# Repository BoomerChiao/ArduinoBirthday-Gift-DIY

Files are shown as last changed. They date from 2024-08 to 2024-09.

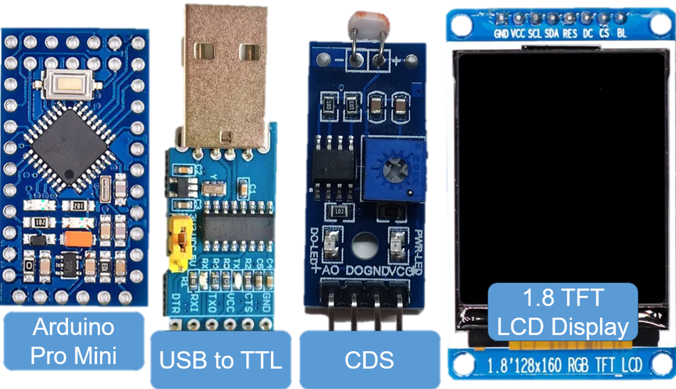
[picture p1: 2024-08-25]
JPG/Materials-A.png

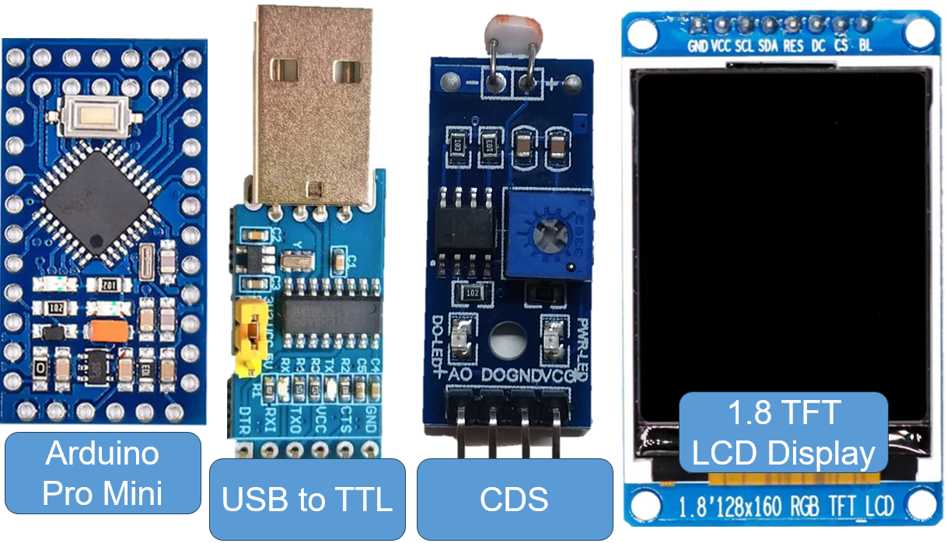
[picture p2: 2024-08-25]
JPG/Materials.png

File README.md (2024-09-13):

##  Summary　（概要）

Arduino Interactive Gifts is a compact interactive gift that features an Arduino Pro Mini microcontroller board, a TFT color LCD screen (supporting 18-bit color depth), and multiple light-dependent resistors (LDRs).

###  中文
Arduino Interactive Gifts 是一款小型互動式禮物，搭載 Arduino Pro Mini 微控制器板和 TFT 彩色液晶顯示螢幕（支持 18 位色深），並配備多顆光敏電阻（LDRs）。

##  Installation　（安裝）
Install Arduino software
- Arduino software downloads：https://www.arduino.cc/en/software
									
###  中文
安裝 Arduino 軟體
- Arduino 軟體下載：https://www.arduino.cc/en/software



##  Import data　（導入資料）
1. Download GitHub Data or Create a New Arduino Project:
   - You can either download the necessary files from GitHub or start a new Arduino project.

2. Include the Required Arduino Libraries:
   - To add extra functionality, move the required Arduino library files to your project. You can download these libraries from the "Library" folder on GitHub.
   - Alternatively, open the Arduino IDE, go to the 「Sketch」 menu, and select 「Include Library」→「Manage Libraries...」 to access and install the libraries.

3. Import the Libraries:
   - After importing the function libraries, select the project you wish to work on and integrate the necessary code.

###  中文
1. 下載 GitHub 資料或創建新 Arduino 專案：
   - 你可以從本網的 GitHub 下載所需的資料，或是自行創建一個新的 Arduino 專案。
    
2. 導入必要的程式函數庫：
   - 將必要的函數庫文件從 GitHub 的“Library”資料夾中下載並安裝至指定位置。
   - 你也可以在 Arduino IDE 中選擇「草稿碼」→「匯入程式庫」→「管理程式庫...」，然後下載所需的程式函數庫。

3. 完成函數庫導入後：
   - 選擇你要製作的專案並直接開啟即可開始使用。

##  Prepare Electronic Materials　（準備電子材料）
1. Arduino Pro Mini (5V/16M)
2. USB to UART Adapter (FTDI or CP2102)
3. TFT LCD Display Module (Icstation 1.8 Inch TFT LCD Screen 128x160 ST7735)
4. CDS (5mm)
5. Jumper Wires


##  Pin wiring　（引腳接線）

⬆The above diagram shows the pin connection schematic.

- Please note that the LCD supports only a 3.3 ~ 5V voltage. Therefore, it is recommended to set the VCC to be powered by a 5V supply.
- The quantity of photoresistors can be adjusted according to specific requirements, with support for up to 3 units.
- The TOUCH button A0 is a Jumper wire.

###  中文
- 請注意，該 LCD 僅持支援 3.3 ~ 5V 電壓範圍。因此，建議將 VCC 預設為 5V 電源以確保正常運作。
- 光敏電阻數量可以根據具體需求進行調整。（最多支援 3 顆）
- 觸控按鈕 (TOUCH) A0是一根跳線。

##  Program Code　（程式代碼）
This project utilizes online-provided code libraries for management and display. To ensure that the code runs correctly, please install the 「Adafruit ST7735 and ST7789 Library」 and 「ADCTouch」 in advance.

This code provides three different programming approaches. You can choose the most suitable option based on your needs to develop your final product. Below is an overview of the differences between each code option:
1. Arduino_TFT：
   - Features: Provides basic TFT display animation technology and ADCTouch interaction.
   - Use Case: Suitable for applications that require basic display and touch functionalities.
  
2. Arduino_TFT_CDS：
   - Features: Builds on the basic TFT display animation and ADCTouch interaction, with the addition of a Light Dependent Resistor (CDS) to detect ambient light levels and automatically adjust the display's on/off state.
   - Use Case: Ideal for applications that require ambient light detection and automatic display control.
  
3. Arduino_TFT_CDS_CPUandReset：
   - Features: Expands upon the basic TFT display animation and ADCTouch interaction by incorporating a CDS sensor to detect ambient light and automatically control the display's power state. Additionally, when the display is off, the system activates a low-power CPU mode to extend battery life.
   - Use Case: Suitable for applications requiring light detection, automatic display control, and power-saving features.

You can download the code from the following link：https://github.com/BoomerChiao/ArduinoBirthday-Gift-DIY/tree/main/Code

###  中文
本次專題採用了網上提供程式數據庫進行管理和顯示，為了確保代碼能夠正確運行，請事先安裝以下程式庫：
1. Adafruit ST7735 Library
   - 用途：提供 ST77xx TFT 顯示模組的控制支持。
   - 安裝方式如下
     - 打開 Arduino IDE 點擊「工具」 > 「管理庫...」。
     - 在程式庫管理器的搜索框中輸入 "Adafruit ST7735"。
     - 在搜尋結果中找到 "Adafruit ST7735 and ST7789 Library" 點擊 「安裝」 按鈕。
     

2. ADCTouch Library
   - 用途：用於讀取觸控傳感器的數據。
   - 安裝方式如下
     - 打開 Arduino IDE 點擊「工具」 > 「管理庫...」。
     - 在程式庫管理器的搜索框中輸入 "ADCTouch"。
     - 在搜尋結果中找到 "ADCTouch" 點擊 「安裝」 按鈕。
     

該代碼提供3種不同的程式方式，你可以根據需求選擇最適合的方式來製作你的最終產品。以下是每種程式碼選項的差異介紹：
1. Arduino_TFT：
   - 功能：提供基本的 TFT 顯示動畫技術和 ADCTouch 觸控互動。
   - 適用場景：適合需要基本顯示和觸控功能的應用。
2. Arduino_TFT_CDS：
   - 功能：基於基本 TFT 顯示動畫和 ADCTouch 觸控互動的基礎上，增加了光敏電阻（CDS）來檢測環境光源，並決定是否自動調節顯示螢幕的開關狀態。
   - 適合需要環境光檢測以及顯示螢幕自動控制的應用場景。
3. Arduino_TFT_CDS_CPUandReset：
   - 功能：在基本 TFT 顯示動畫和 ADCTouch 觸控互動的基礎上，增加了光敏電阻（CDS）以檢測環境光源並自動控制顯示螢幕開關。此外，當顯示螢幕關閉時，系統將啟用低功耗的 CPU 模式，以提高電池續航能力。
   - 適用於需要光檢測、自動顯示控制和節能功能的應用。

你可以從以下鏈接下載代碼：https://github.com/BoomerChiao/ArduinoBirthday-Gift-DIY/tree/main/Code

.

.

P.S. 其他安裝Library
   - 打開 Arduino IDE 點擊「sketch」 > 「程式庫」 > 「加入.Zip程式庫...」。
   - 搜尋 已下載Zip程式庫 ，點擊 「開啟」 按鈕。

P.S. Code is customizable （可自定義代碼）

1. (TFT_sleep=75) This parameter sets the brightness threshold for the light-dependent resistor (CDS) to determine the on/off state of the display (TFT). 
（參數用於設定光敏電阻 (CDS) 的亮度閾值，以決定顯示器 (TFT) 的開關狀態。）

   - A higher value indicates that a greater ambient light level is required to keep the display on, meaning the display will stay on in bright conditions. Conversely, a lower value will cause the display to remain on even in lower light conditions.
     （數值越大，表示所需的環境亮度越高，顯示器在光線充足時將保持開啟；數值越小，則顯示器在光線較弱時也會開啟。）
   - If the parameter is set to -1, the light-dependent resistor (CDS) is disabled, and the display will remain on at all times.
     （若參數設定為 -1，則光敏電阻 (CDS) 會被禁用，顯示器將始終保持開啟狀態。）

3. (walk_delay=230) This parameter adjusts the delay time for character movement. A smaller value results in faster movement, while a larger value slows down the movement.
   （參數用於調整人物行走的延遲時間。數值越小，人物行走的速度越快；數值越大，人物行走的速度則越慢。）

##  Arduino Pro or Pro Mini USB to UART Hookup Guide　（Arduino Pro、Pro Mini USB 燒入連接指南）
The Arduino Pro Mini and Arduino Pro are compact, low-power versions of the Arduino board. To program these boards or communicate with them via a computer, you'll need a USB-to-UART (Universal Asynchronous Receiver/Transmitter) adapter.


Picture from：https://www.b4x.com/android/forum/threads/how-to-connect-an-arduino-pro-mini-to-a-pc-via-a-usb-to-serial-module.77010/
1. Steps to Connections
   - USB-to-UART Adapter VCC → Arduino Pro Mini VCC
     - USB-to-UART Adapter Pins Connect to Arduino Pro Mini VCC (make sure it matches the voltage of your Pro Mini)
   - USB-to-UART Adapter GND → Arduino Pro Mini GND
   - USB-to-UART Adapter TX → Arduino Pro Mini RX
   - USB-to-UART Adapter RX → Arduino Pro Mini TX
   - USB-to-UART Adapter DTR → Arduino Pro Mini DTR
2. Troubleshooting Tips
   - Check Connections： Ensure all wires are connected securely and to the correct pins.
   - Verify Voltage： Make sure the VCC connection matches the voltage requirements of your Pro Mini.
   - Auto-reset： If uploading code fails, try manually pressing the reset button on the Pro Mini just before uploading.

##  Advanced Design　（進階設計）
To simplify the electronic manufacturing process, we employed the printed etch resist method to handle complex and difficult-to-connect circuits. This approach not only significantly reduces the risk of incorrect connections but also ensures the effective operation of the product.

Therefore, we utilized the PCB manufacturing services provided by EasyEDA to successfully address the challenges of printed circuit design for this project.

為了簡化電子製作過程，我們採用了印刷蝕刻阻劑工法來處理複雜且難以連接的線路。這樣不僅能大幅度降低錯誤連接的風險，還能確保產品的有效運作。

因此，我們利用了EasyEDA提供的PCB製造服務，成功解決了此專案中的印刷電路設計挑戰。

You can obtain the PCB layout from the following link（你可以從下鏈結獲得PCB layout）：https://oshwlab.com/chiaochieh/dinotaeng_gift_2024-06-04_21-21-12

###  Circuit Design （電路設計）
   

###  PCB layout （電路布局）
   

###  PCB Prepare Electronic Materials　（PCB準備電子材料）
1. SMD MLCC 
   - C1、C4、C8：100nF-1206
   - C2、C3、C7、C9：10uF-1206
   - C5：47uf-50v or 100uf-25v or N/A

2. SMD Resistors
   - R1：130Ω-1206
   - R2：390Ω-1206
   - R3、R4：5.1KΩ-1206
   - R5、R6、R7：GL7537 or 5mm_CDS
   - R8、R9、R10：1KΩ-1206
   - F1：TLC-MSMD160/6 or 0Ω-1812

3. DIP Connectors 
   - P1、P2、P4：N/A
   - P3：2.54mm Plugin Straight Headers Connector 2x7P、1x10P、1x10P
   - P5：2.54mm Plugin 8P Straight 1x8P Headers Connector
   - P6、P7：2.54mm Plugin 3P Straight 1x3P Pin Headers or 3P slide switch
   - P8：2.54mm Plugin 2P Straight 1x2P Pin Headers

4. SMD Active component
   - D1：SS34 (SMA) or 1N4007_SMD (M7 or SMA)
   - U1：AMS1117-ADJ
   - U2：AMS1117-3.3
   - TVS：SMBJ5.0CA or N/A

5. Power Connector
   - USB：KH-TYPE-C-6P-T or SMD TYPE C 6P
   - DC:XDJK-0051-025 or DIP DC Power Connectors (2.1mm 6.3mm)

###  3D casing （3D外殼）
To facilitate wiring and prevent cable damage, the V1 version includes dedicated cable routing openings.
（為了提高布線的便利性並減少線材損壞的風險，V1版本設計了專用的走線開口。）



You can obtain the 3D printed shell from the following link（你可以從下鏈結獲得3D外殼）：
https://www.thingiverse.com/thing:6763818

##  Product Showcase　（成品展示）
















##  References　（參考資料）
1. https://www.arduino.cc/en/software
2. https://www.b4x.com/android/forum/threads/how-to-connect-an-arduino-pro-mini-to-a-pc-via-a-usb-to-serial-module.77010/
3. https://github.com/adafruit/Adafruit-ST7735-Library
4. https://github.com/martin2250/ADCTouch

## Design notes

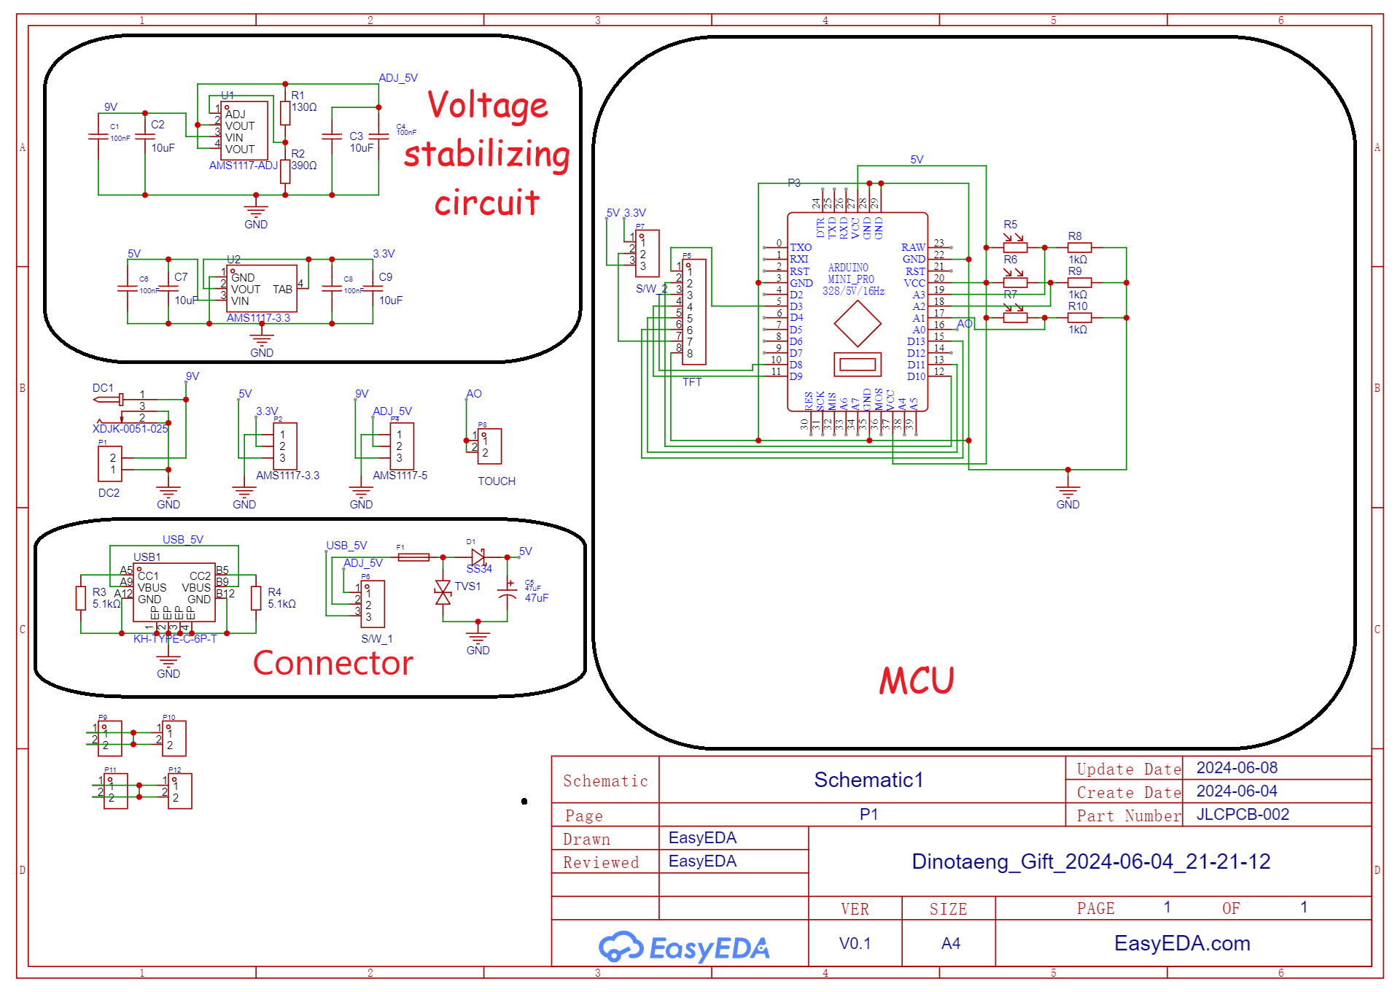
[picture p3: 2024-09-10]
JPG/Circuit.png

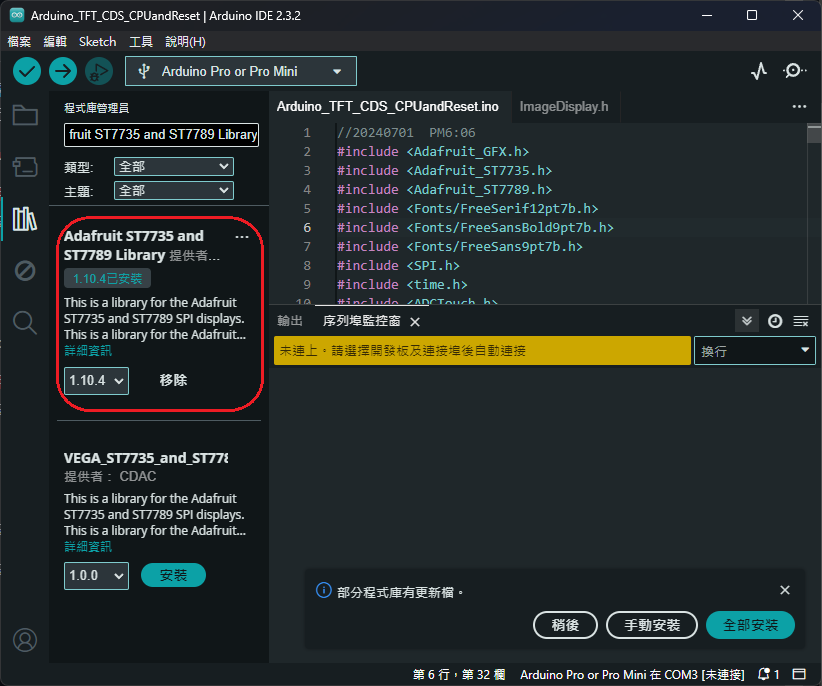
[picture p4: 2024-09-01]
JPG/Library_A.png

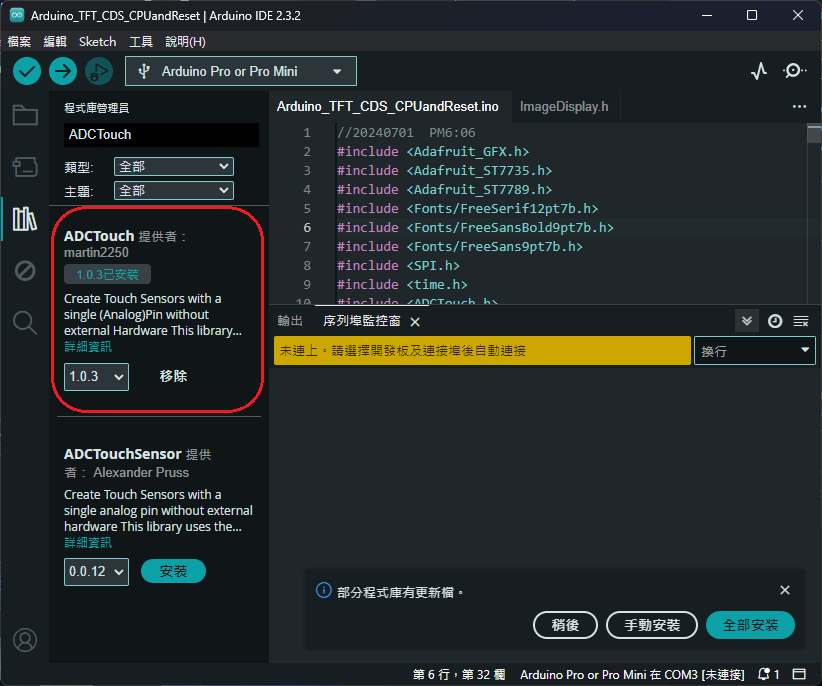
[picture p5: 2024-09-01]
JPG/Library_B.png

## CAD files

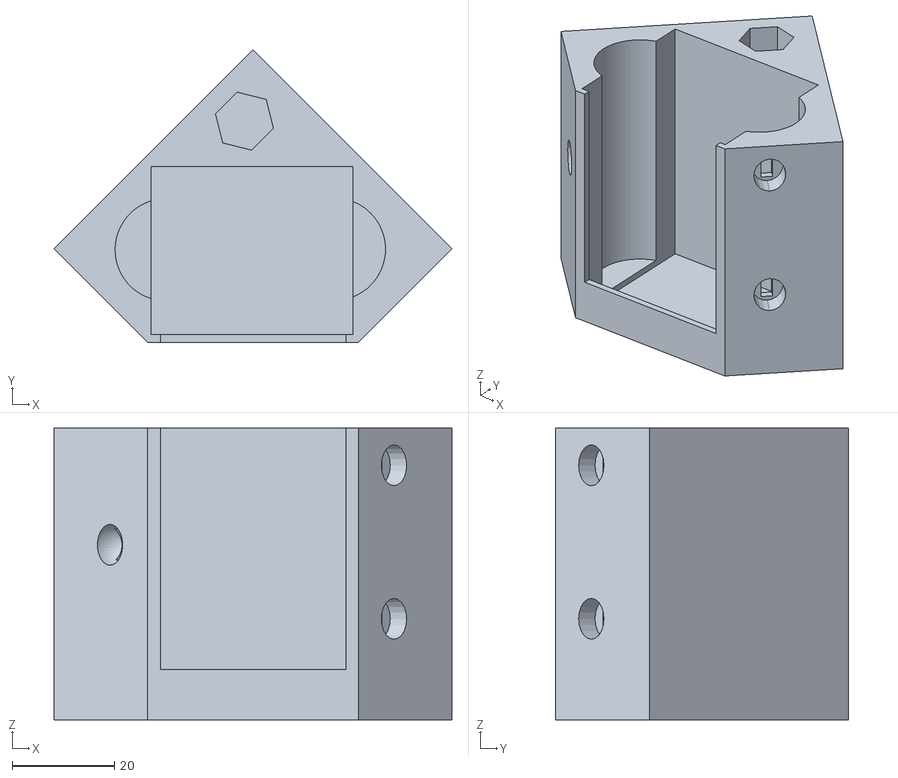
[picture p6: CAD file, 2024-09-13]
3D Printing/3D_printed_shell_A_V1.stl
77.8 x 57.2 x 57.0

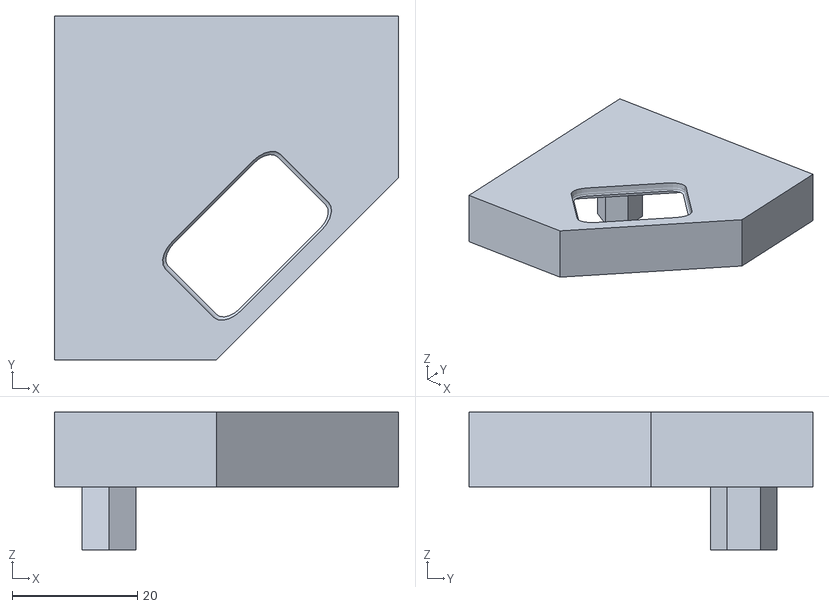
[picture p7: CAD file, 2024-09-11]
3D Printing/3D_printed_shell_B.stl
55.0 x 55.0 x 22.0

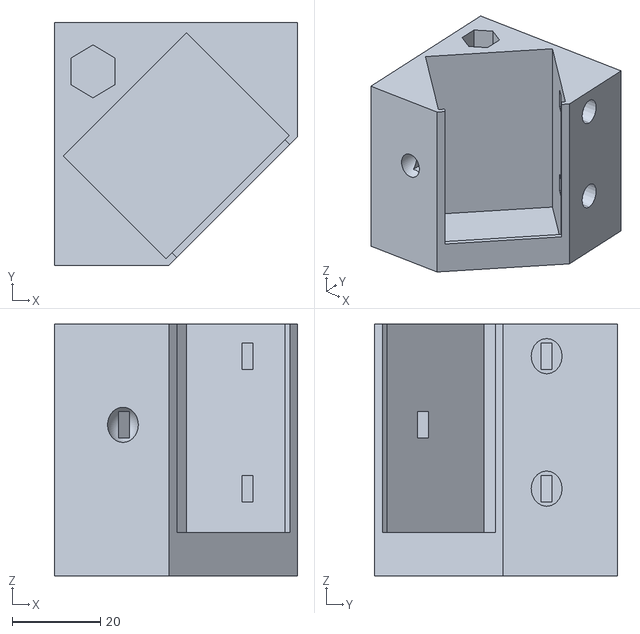
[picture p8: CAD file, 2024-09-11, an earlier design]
3D Printing/3D_printed_shell_A.stl
55.0 x 55.0 x 57.0

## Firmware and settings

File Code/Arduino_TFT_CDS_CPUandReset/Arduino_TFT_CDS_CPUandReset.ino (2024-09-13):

//20240701  PM6:06
#include <Adafruit_GFX.h>
#include <Adafruit_ST7735.h>
#include <Adafruit_ST7789.h>
#include <Fonts/FreeSerif12pt7b.h>
#include <Fonts/FreeSansBold9pt7b.h>
#include <Fonts/FreeSans9pt7b.h>
#include <SPI.h>
#include <time.h>
#include <ADCTouch.h>
#include <avr/wdt.h> //watchdog 
#include "ImageDisplay.h"
#define TFT_CS  10 // TFT CS PIN
#define TFT_DC   8 // TFT DC(A0、RS) 
#define TFT_RST  9 // TFT Reset

int walk=0,Gift_X,Gift_Y,time_sun_moon; 
int CDS_A,CDS_B,CDS_C,CDS_Time=0 ,TFT_sleep=75; //CDS The higher the value, the stronger the light source required.
int TOUCH_A0;     //reference values to remove offset
int walk_delay=230; //Modify the timing of the steps
bool Gift_bool = false , sun_moon=false , TFT_sleep_bool=true;   //true,false

Adafruit_ST7735 tft = Adafruit_ST7735(TFT_CS, TFT_DC, TFT_RST);


void setup(void) {
  
  
  // 1.8" TFT:
  tft.initR(INITR_BLACKTAB);      // Init ST7735S chip, black tab

  // 1.44" TFT:
  //tft.initR(INITR_144GREENTAB); // Init ST7735R chip, green tab


  srand( time(NULL) );
  TOUCH_A0 = ADCTouch.read(A0, 200);
  tft.setRotation(1);  //螢幕轉向 screen orientation
  tft.fillScreen(ST77XX_BLACK);  //填滿黑色
  tft.fillRect(0, 0, 160, 87,0x6358); //Sky
  tft.fillRect(0, 87, 160, 41,0x0568); //floor
  pinMode(3,OUTPUT); //TFT BLK on/off
  wdt_enable(WDTO_8S); //Watchdog 
  digitalWrite(3,LOW);

}

void loop() {
  int value0 = ADCTouch.read(A0);   //no second parameter
  value0 -= TOUCH_A0;       //remove offset
  CDS_A = analogRead(A1);CDS_B = analogRead(A2);CDS_C = analogRead(A3);

  if (TFT_sleep_bool==false || CDS_A>TFT_sleep || CDS_B>TFT_sleep || CDS_C>TFT_sleep)
  {

    CLKPR = 1 << CLKPCE;
    CLKPR = 0;// 將CPU速度設定為 16MHz/1   Set the CPU speed to 16 MHz / 1
    sun_moon_display();
    Quokka_BOBO_display();

  if(value0 > 60 && Gift_bool == true ) //Touch A0
  {
  Gift_display();
  }
  if(CDS_A<=TFT_sleep && CDS_B<=TFT_sleep && CDS_C<=TFT_sleep)
  {
    CDS_Time = CDS_Time+1;
    if(CDS_Time>5)
    {
      TFT_sleep_bool=true;
      CDS_Time=0;
    }} 
    else
    {
      CDS_Time=0;
      TFT_sleep_bool=false;
    } 
    
    digitalWrite(3,HIGH);
    }
  else if (TFT_sleep_bool==true && CDS_A<=TFT_sleep && CDS_B<=TFT_sleep && CDS_C<=TFT_sleep)
  {
    digitalWrite(3,LOW);
    CLKPR = 1 << CLKPCE;
    CLKPR = 8;// 將CPU速度設定為 62.5KMHz/256  Set the CPU speed to 62.5 KHz / 256
  }
  wdt_reset();
  }




void Quokka_BOBO_display(void)
{
  if(walk>160) 
  {
    walk=-68;
    Gift_bool = true;
    Gift_X= rand()%(143 - 1 + 1) + 1; // (max - min + 1) + min
    Gift_Y= rand()%(31 - 1 + 1) + 1; // (max - min + 1) + min
    tft.drawRGBBitmap(Gift_X, Gift_Y+88,Gift, 16, 7);
    //tft.drawRGBBitmap(0, 0,Gift, 16, 7);
    //tft.fillRect(0, 0, 18, 9,ST77XX_GREEN);
  }

  tft.fillRect(walk+0, 39, 11, 48,0x6358);
  tft.drawRGBBitmap(walk+0, 40,BB, 32, 31);
  //tft.drawRGBBitmap(walk+11, 71,BC, 26, 16);//x,y,png,xx,yy
  tft.drawRGBBitmap(walk+11, 71,BD, 26, 16);

  tft.fillRect(walk+31, 59, 10, 13,0x6358);
  tft.drawRGBBitmap(walk+36, 60,DB, 20, 13);
  //tft.drawRGBBitmap(walk+37, 71,DC, 18, 14);
  tft.drawRGBBitmap(walk+37, 73,DD, 18, 14);
  //delay(230);
  delay(walk_delay);

/*tft.drawRGBBitmap(walk+11, 71,BD, 26, 16);
  tft.drawRGBBitmap(walk+37, 71,DD, 18, 14);*/
  tft.drawRGBBitmap(walk+11, 71,BC, 26, 16);
  tft.drawRGBBitmap(walk+37, 73,DC, 18, 14);
  //delay(230);
  delay(walk_delay);
  tft.fillRect(walk+0, 39, 11, 48,0x6358);
  walk=walk+8;
  //tft.fillRect(walk+31, 58, 10, 13,ST77XX_BLACK);
}


void sun_moon_display(void)
{
  tft.fillRect(time_sun_moon*2.7-2, 0, 22, 30,0x6358); //Reset sun_moon track
  time_sun_moon=time_sun_moon+1; //sun_moon time
  
  if(time_sun_moon>60)
  {
    time_sun_moon=-10  ;
    if(sun_moon == false)
    {
      sun_moon = true;
      tft.fillRect(0, 0, 160, 30,0x6358);
    }
    else
    {
      sun_moon = false;
    }
  }
  
  
  if(sun_moon == false)
  {
    Gift_X= rand()%(160 - 1 + 1) + 1; // (max - min + 1) + min
    Gift_Y= rand()%(28 - 1 + 1) + 1; // (max - min + 1) + min
    //tft.drawRGBBitmap(Gift_X, Gift_Y+88,Gift, 16, 7);
    tft.fillCircle(Gift_X, Gift_Y, 1, ST77XX_WHITE); 
    //tft.drawRGBBitmap(time_sun_moon*2.7-10, 3,sun_moon_B, 11, 22);
    tft.drawRGBBitmap(time_sun_moon*2.7, 3,sun_moon_B, 22, 22);
  }
  else
  {
    //tft.fillRect(0, 3, 160, 24,0x6358);
    tft.drawRGBBitmap(time_sun_moon*2.7, 3,sun_moon_A, 22, 22);
  }
}


void Gift_display(void)
{
    //tft.drawRGBBitmap(0, 0,Gift, 16, 7);
  Gift_bool = false;
  tft.fillScreen(ST77XX_BLACK);
    //tft.fillRect(0, 87, 160, 41,0x0568);
  tft.fillRect(10, 25, 140, 30,0xfe41);
  tft.fillRect(10, 55, 140, 48,0xe8e4);
  tft.fillRect(65, 25, 30, 78,0xbbca);
    //tft.fillRect(10, 20, 140, 98,ST77XX_YELLOW);
  delay(1000);
  tft.fillRect(10, 25, 140, 30,ST77XX_BLACK);
  tft.fillRect(10, 5, 140, 30,0xfe41);
  delay(1500);
    //tft.fillScreen(ST77XX_BLACK);
  tft.fillScreen(0x6358);
  tft.setCursor(50, 40);  //設定文字游標點
  tft.setTextColor(ST77XX_WHITE);  //設定文字顏色
  tft.setFont(&FreeSerif12pt7b);  //字型
  tft.print("Happy");  //顯示文字
  tft.setCursor(40, 70);  //設定文字游標點
  tft.print("Birthday !");  //顯示文字

  tft.drawRGBBitmap(50, 77,BB, 32, 31);
  tft.drawRGBBitmap(61, 108,BD, 26, 16);

  tft.drawRGBBitmap(86, 97,DB, 20, 13);
  tft.drawRGBBitmap(87, 110,DD, 18, 14);
  delay(2500);
  tft.drawRGBBitmap(61, 108,BC, 26, 16);
  tft.drawRGBBitmap(87, 110,DC, 18, 14);
  delay(1500);

    //tft.fillScreen(ST77XX_BLACK);
  tft.fillScreen(0x6358);
  tft.fillRect(0, 87, 160, 41,0x0568);
}

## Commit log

2024-08-25 Update README.md
    Arduino Pro or Pro Mini USB to UART Hookup Guide
2024-08-25 Prepare Electronic Materials JPG
2024-09-11 3D Printing
    3D Printing
    [3D_printed_shell_A.stl, 3D_printed_shell_B.stl]
2024-09-13 Update Arduino_TFT_CDS_CPUandReset.ino
    time
